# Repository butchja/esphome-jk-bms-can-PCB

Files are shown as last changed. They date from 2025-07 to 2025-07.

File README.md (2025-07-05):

It is recommended to reflow solder with solder paste and stencil. 

Features
- small single board solution
- CAN is now 5V as required by standard
- power supply is compatible to battery voltages now

Materials required
- antenna cable: MHF3 to RP-SMA breakout cable 7cm
- wifi antenna
- BMC cable: JST XH 2.5mm - JST SH 1.25mm
- 2pcs M5 nuts
- 2pc M5x10 screws
- 4pcs M3x5 threaded inserts
- 4pcs M3x6 screws
  



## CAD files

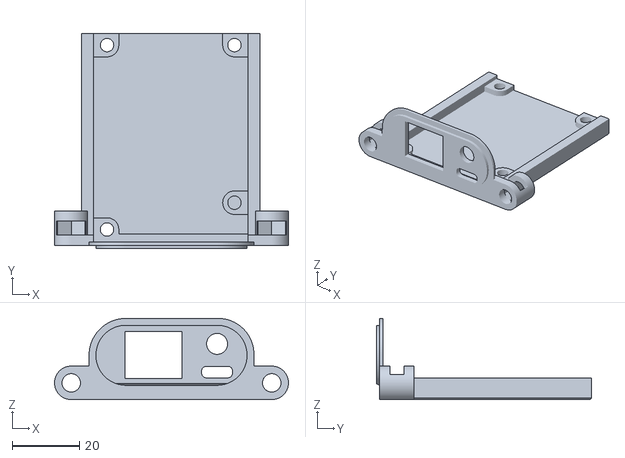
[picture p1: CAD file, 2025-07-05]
HJDC_enclosure_mount.stl
69.8 x 64.2 x 24.2

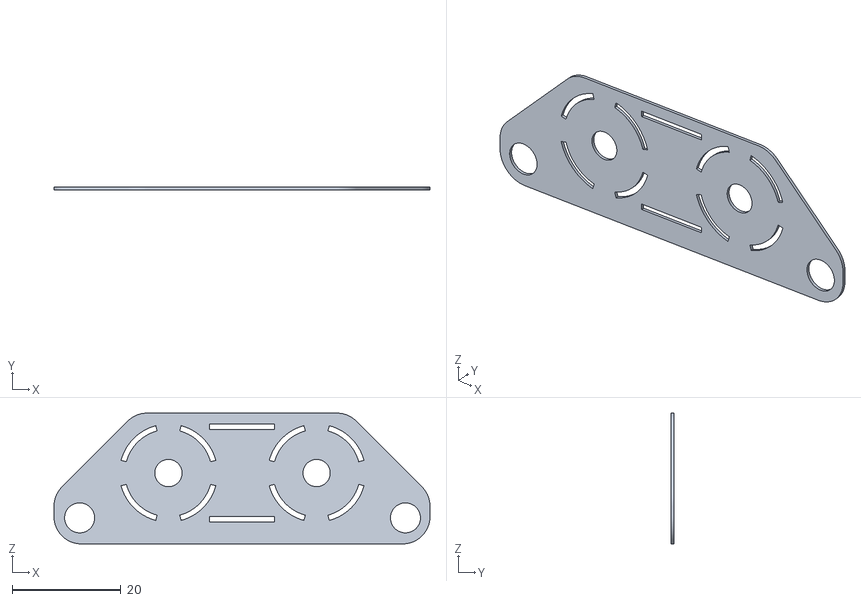
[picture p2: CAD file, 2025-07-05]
HJDC_drillpattern.stl
69.0 x 0.503 x 24.0

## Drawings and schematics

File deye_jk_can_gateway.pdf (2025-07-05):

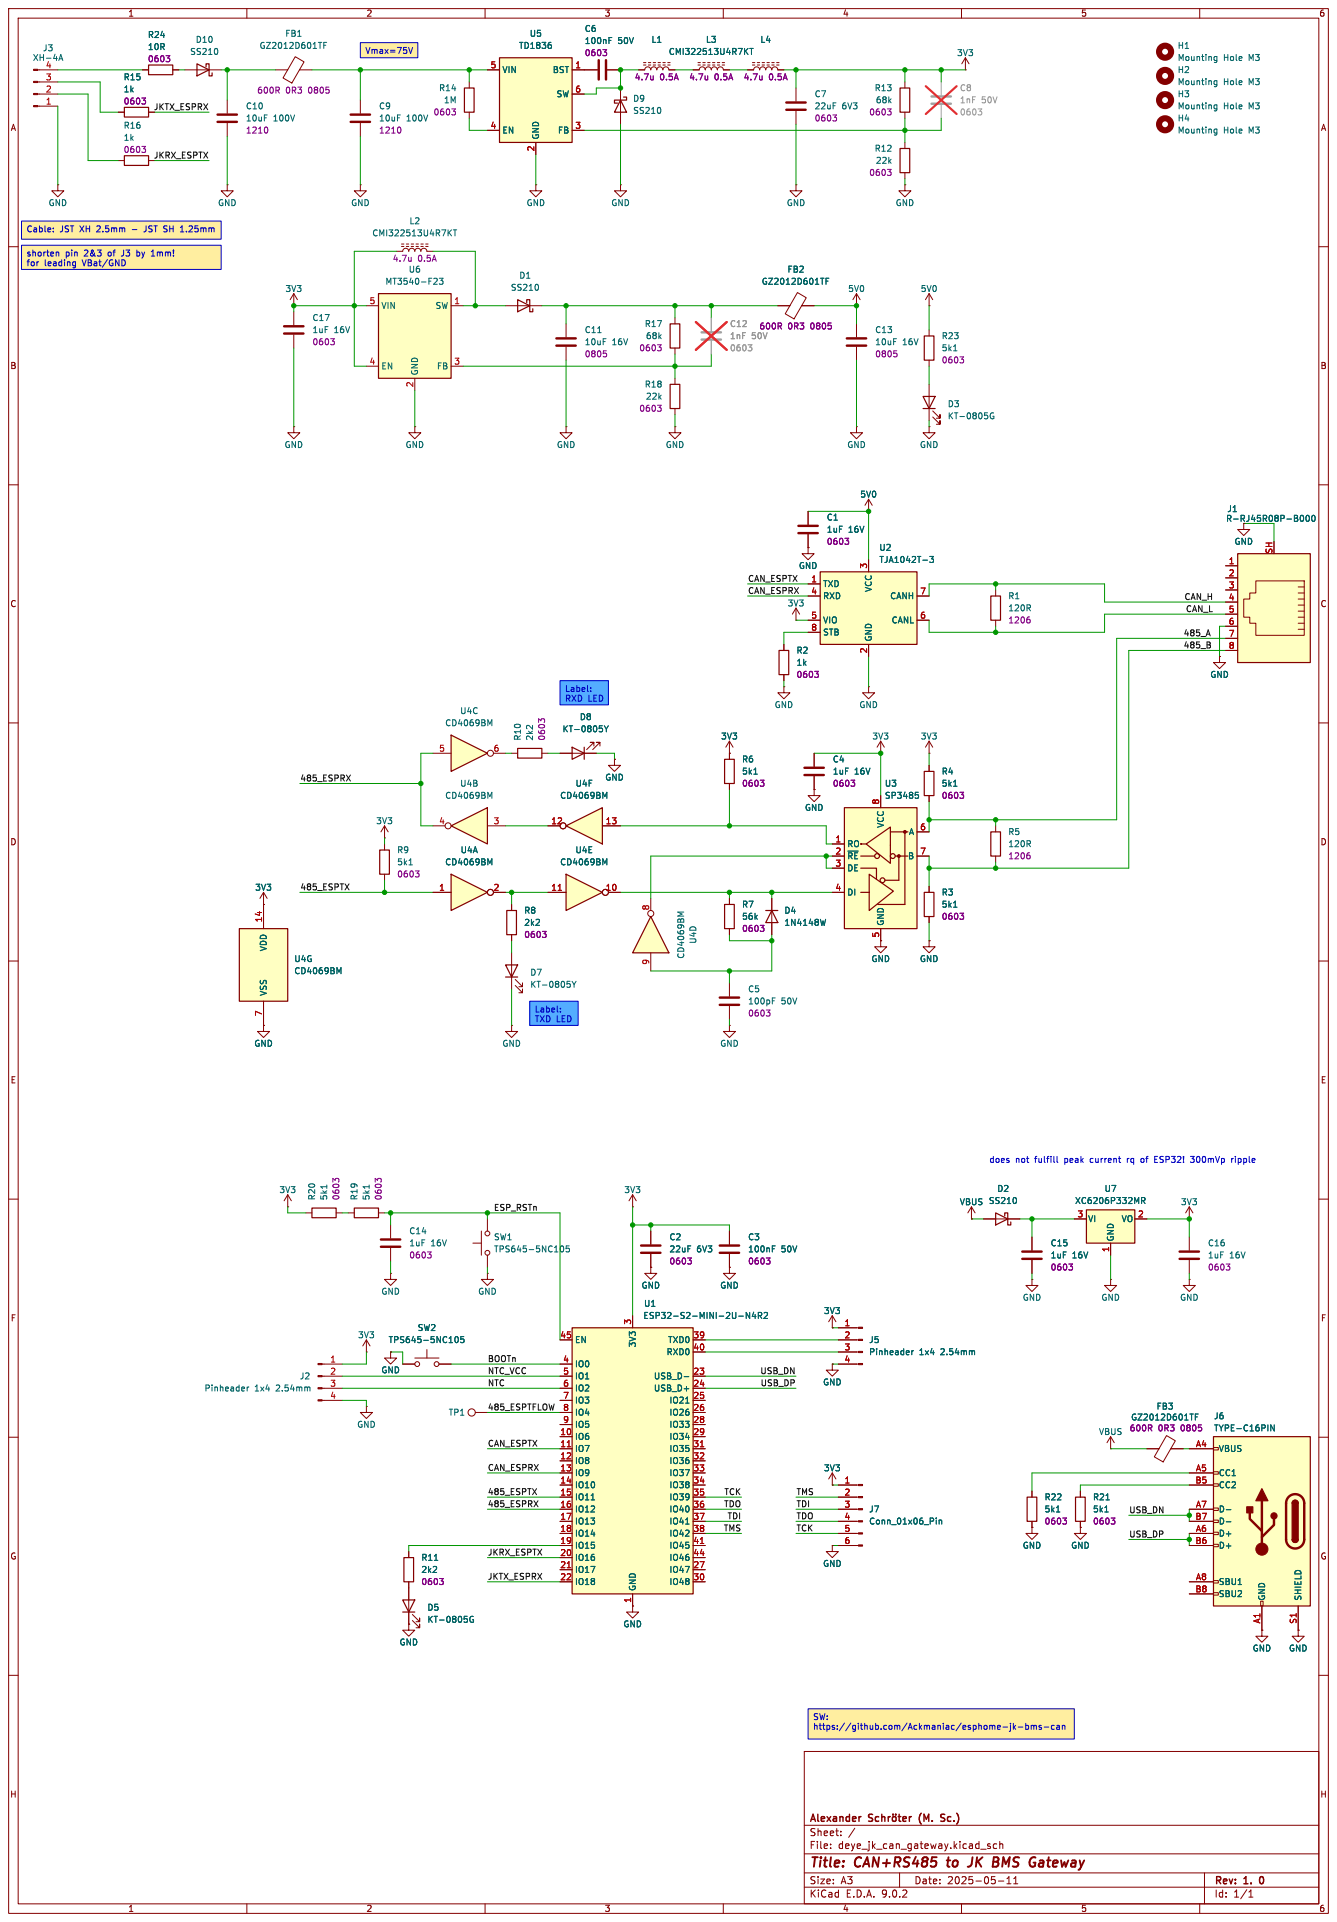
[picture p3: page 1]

2 BST 1 SW 6 FB 3 U5 TD1836 GND GND
Vmax=75V
3V3 GND

Cable: JST XH 2.5mm - JST SH 1.25mm

shorten pin 2&3 of J3 by 1mm!
for leading VBat/GND

SW: https://github.com/Ackmaniac/esphome-jk-bms-can

File: deye_jk_can_gateway.kicad_sch Sheet: / Alexander þÿSchröter (M. Sc.)

Id: 1/1 Title: CAN+RS485 to JK BMS Gateway

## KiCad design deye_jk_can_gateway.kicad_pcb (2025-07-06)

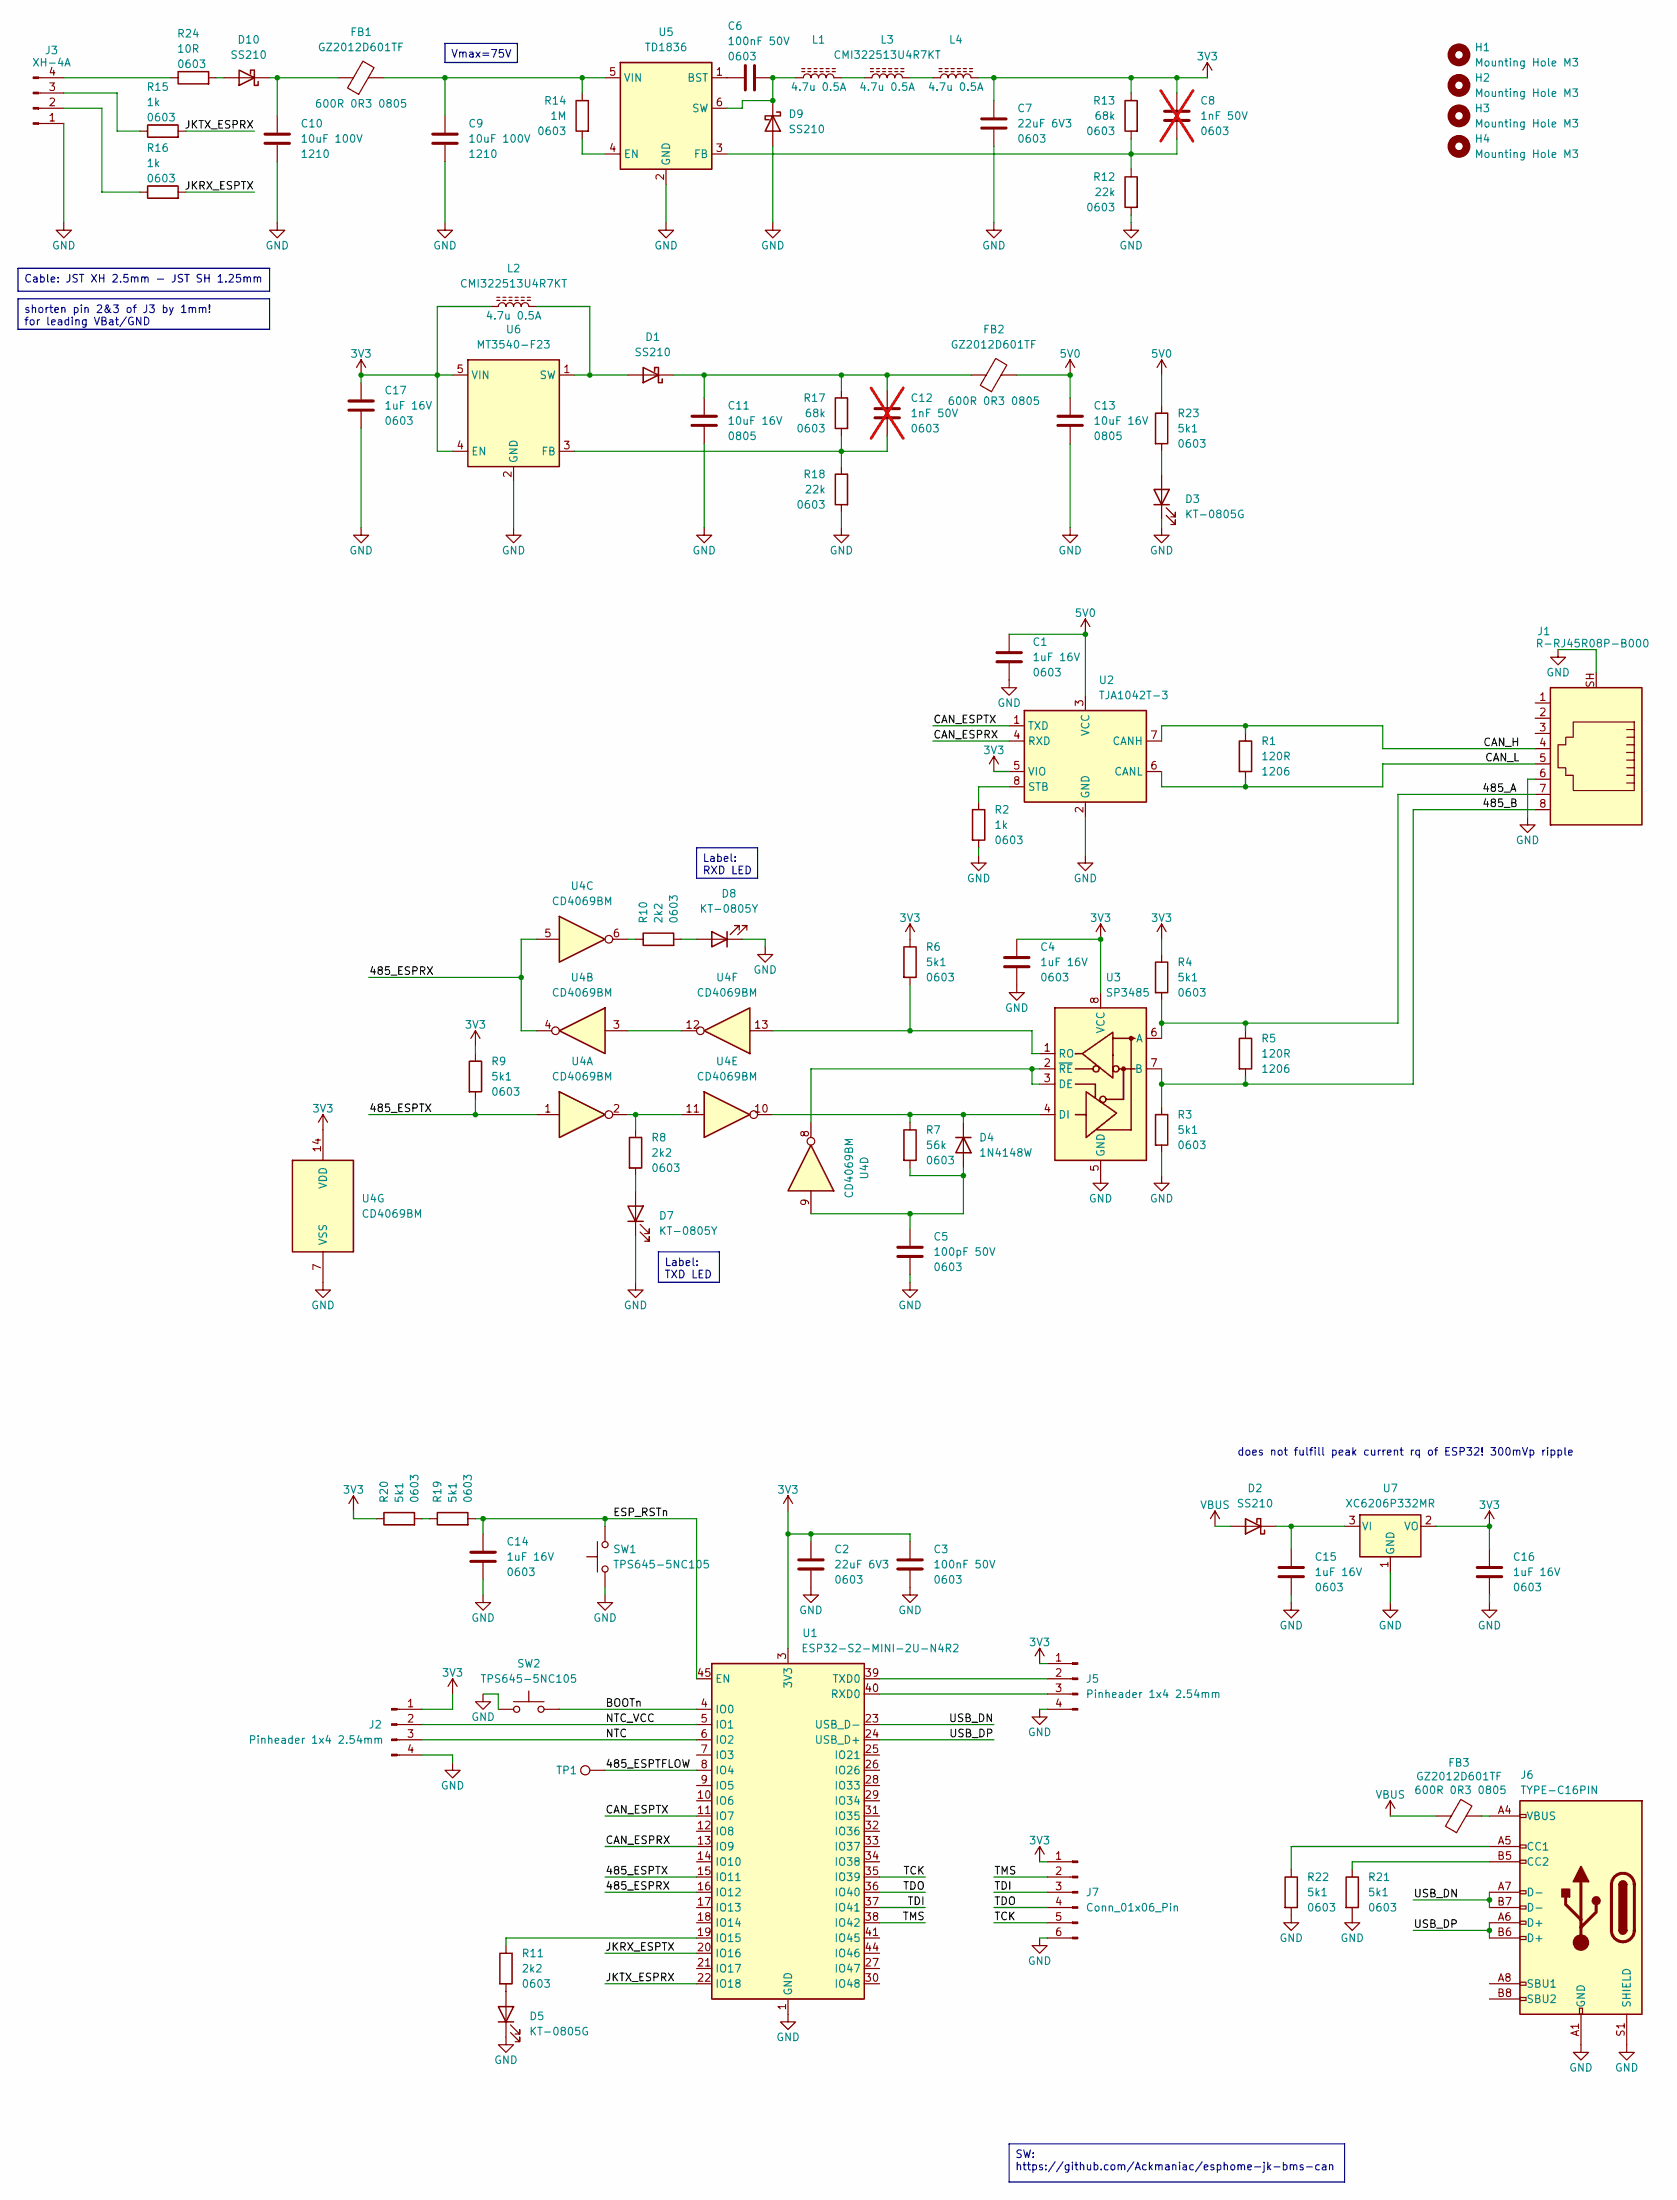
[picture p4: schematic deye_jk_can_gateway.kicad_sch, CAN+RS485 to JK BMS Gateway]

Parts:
C1, C4, C14, C15, C16, C17: 1uF 16V; C_0603_1608Metric; LCSC C1592
C2, C7: 22uF 6V3; C_0603_1608Metric; LCSC C59461
C3, C6: 100nF 50V; C_0603_1608Metric; LCSC C1591
C5: 100pF 50V; C_0603_1608Metric; LCSC C14858
C8, C12: 1nF 50V; C_0603_1608Metric; LCSC C1588; not fitted
C9, C10: 10uF 100V; C_1210_3225Metric; LCSC C576517
C11, C13: 10uF 16V; C_0805_2012Metric; LCSC C1713
D1, D9: SS210; D_SMA
D2, D10: SS210; D_SMA; LCSC C14996
D3, D5: KT-0805G; LED_0805_2012Metric; LCSC C2297
D4: 1N4148W; D_SOD-123; LCSC C2099
D7, D8: KT-0805Y; LED_0805_2012Metric; LCSC C2296
FB1, FB2, FB3: GZ2012D601TF; L_0805_2012Metric; LCSC C1017
H1, H2, H3, H4: Mounting Hole M3; MountingHole_3.2mm_M3_ISO7380
J1: R-RJ45R08P-B000; RJ45_Amphenol_RJHSE5380; LCSC C386756
J2, J5: Pinheader 1x4 2.54mm; PinHeader_1x04_P2.54mm_Vertical
J3: XH-4A; JST_XH_B4B-XH-A_1x04_P2.50mm_Vertical
J6: TYPE-C16PIN; USB_C_Receptacle_GCT_USB4105-xx-A_16P_TopMnt_Horizontal; LCSC C393939
J7: Conn_01x06_Pin; PinHeader_1x06_P2.54mm_Vertical
L1, L2, L3, L4: CMI322513U4R7KT; L_1210_3225Metric; LCSC C60534
R1, R5: 120R; R_1206_3216Metric; LCSC C17909
R2, R15, R16: 1k; R_0603_1608Metric; LCSC C21190
R3, R4, R6, R9, R19, R20, R21, R22, R23: 5k1; R_0603_1608Metric; LCSC C23186
R7: 56k; R_0603_1608Metric; LCSC C23206
R8, R10, R11: 2k2; R_0603_1608Metric; LCSC C4190
R12, R18: 22k; R_0603_1608Metric; LCSC C31850
R13, R17: 68k; R_0603_1608Metric; LCSC C23231
R14: 1M; R_0603_1608Metric; LCSC C22935
R24: 10R; R_0603_1608Metric; LCSC C21190
SW1, SW2: TPS645-5NC105; SW_SPST_PTS645; LCSC C19191549
TP1: TestPoint; TestPoint_Pad_1.0x1.0mm
U1: ESP32-S2-MINI-2U-N4R2; ESP32-S2-MINI-1U; LCSC C3013909
U2: TJA1042T-3; SOIC-8_3.9x4.9mm_P1.27mm; LCSC C132227
U3: SP3485; SOIC-8_3.9x4.9mm_P1.27mm; LCSC C8963
U4: CD4069BM; SOIC-14_3.9x8.7mm_P1.27mm; LCSC C22384785
U5: TD1836; SOT-23-6; LCSC C2935198
U6: MT3540-F23; SOT-23-5; LCSC C181783
U7: XC6206P332MR; SOT-23-3; LCSC C5446

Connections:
3V3: C2.1, C3.1, C4.1, C7.1, C8.1, C16.1, C17.1, J2.1, J5.1, J7.1, L2.1, L4.2, R4.1, R6.1, R9.1, R13.1, R20.1, U1.3 (3V3), U2.5 (VIO), U3.8 (VCC), U4.14 (VDD), U6.4 (EN), U6.5 (VIN), U7.2 (VO)
5V0: C1.1, C13.1, FB2.2, R23.1, U2.3 (VCC)
/485_A: J1.7, R4.2, R5.1, U3.6 (A)
/485_B: J1.8, R3.1, R5.2, U3.7 (B)
/485_ESPRX: U1.16 (IO12), U4.4, U4.5
/485_ESPTFLOW: TP1.1, U1.8 (IO4)
/485_ESPTX: R9.2, U1.15 (IO11), U4.1
/BOOTn: SW2.2, U1.4 (IO0)
/CAN_ESPRX: U1.13 (IO9), U2.4 (RXD)
/CAN_ESPTX: U1.11 (IO7), U2.1 (TXD)
/CAN_H: J1.4, R1.1, U2.7 (CANH)
/CAN_L: J1.5, R1.2, U2.6 (CANL)
/ESP_RSTn: C14.1, R19.2, SW1.2, U1.45 (EN)
/JKRX_ESPTX: R16.2, U1.20 (IO16)
/JKTX_ESPRX: R15.2, U1.22 (IO18)
/NTC: J2.3, U1.6 (IO2)
/NTC_VCC: J2.2, U1.5 (IO1)
/TCK: J7.5, U1.35 (IO39)
/TDI: J7.3, U1.37 (IO41)
/TDO: J7.4, U1.36 (IO40)
/TMS: J7.2, U1.38 (IO42)
/USB_DN: J6.A7 (D-), J6.B7 (D-), U1.23 (USB_D-)
/USB_DP: J6.A6 (D+), J6.B6 (D+), U1.24 (USB_D+)
GND: C1.2, C2.2, C3.2, C4.2, C5.2, C7.2, C9.2, C10.2, C11.2, C13.2, C14.2, C15.2, C16.2, C17.2, D3.1 (K), D5.1 (K), D7.1 (K), D8.1 (K), D9.2 (A), J1.6, J1.SH, J2.4, J3.1, J5.4, J6.A1 (GND), J6.A12 (GND), J6.B1 (GND), J6.B12 (GND), J6.S1 (SHIELD), J7.6, R2.2, R3.2, R12.2, R18.2, R21.2, R22.2, SW1.1, SW2.1, U1.1 (GND), U1.2 (GND), U1.42 (GND), U1.43 (GND), U1.46 (GND), U1.47 (GND), U1.48 (GND), U1.49 (GND), U1.50 (GND), U1.51 (GND), U1.52 (GND), U1.53 (GND), U1.54 (GND), U1.55 (GND), U1.56 (GND), U1.57 (GND), U1.58 (GND), U1.59 (GND), U1.60 (GND), U1.61 (GND), U1.62 (GND), U1.63 (GND), U1.64 (GND), U1.65 (GND), U2.2 (GND), U3.5 (GND), U4.7 (VSS), U5.2 (GND), U6.2 (GND), U7.1 (GND)
unnamed: D1.2 (A), L2.2, U6.1 (SW)
unnamed: C11.1, C12.1, D1.1 (K), FB2.1, R17.1
unnamed: C15.1, D2.1 (K), U7.3 (VI)
unnamed: D3.2 (A), R23.2
unnamed: C5.1, D4.2 (A), R7.2, U4.9
unnamed: D4.1 (K), R7.1, U3.4 (DI), U4.10
unnamed: D5.2 (A), R11.2
unnamed: D7.2 (A), R8.2
unnamed: D8.2 (A), R10.2
unnamed: C6.2, D9.1 (K), L1.1, U5.6 (SW)
unnamed: D10.2 (A), R24.2
unnamed: C10.1, D10.1 (K), FB1.1
unnamed: FB3.2, J6.A4 (VBUS), J6.A9 (VBUS), J6.B4 (VBUS), J6.B9 (VBUS)
unnamed: J3.2, R16.1
unnamed: J3.3, R15.1
unnamed: J3.4, R24.1
unnamed: J5.2, U1.39 (TXD0)
unnamed: J5.3, U1.40 (RXD0)
unnamed: J6.A5 (CC1), R22.1
unnamed: J6.B5 (CC2), R21.1
unnamed: L1.2, L3.1
unnamed: L3.2, L4.1
unnamed: R8.1, U4.2, U4.11
unnamed: R10.1, U4.6
unnamed: R19.1, R20.2
unnamed: R11.1, U1.19 (IO15)
unnamed: R2.1, U2.8 (STB)
unnamed: U3.2 (~RE), U3.3 (DE), U4.8
unnamed: R6.2, U3.1 (RO), U4.13
unnamed: U4.3, U4.12
unnamed: C6.1, U5.1 (BST)
unnamed: R14.2, U5.4 (EN)
unnamed: C8.2, R12.1, R13.2, U5.3 (FB)
unnamed: C9.1, FB1.2, R14.1, U5.5 (VIN)
unnamed: C12.2, R17.2, R18.1, U6.3 (FB)
VBUS: D2.2 (A), FB3.1

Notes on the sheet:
does not fulfill peak current rq of ESP32! 300mVp ripple
Label: RXD LED
shorten pin 2&3 of J3 by 1mm! for leading VBat/GND
Label: TXD LED
Cable: JST XH 2.5mm - JST SH 1.25mm
SW: https://github.com/Ackmaniac/esphome-jk-bms-can
Vmax=75V

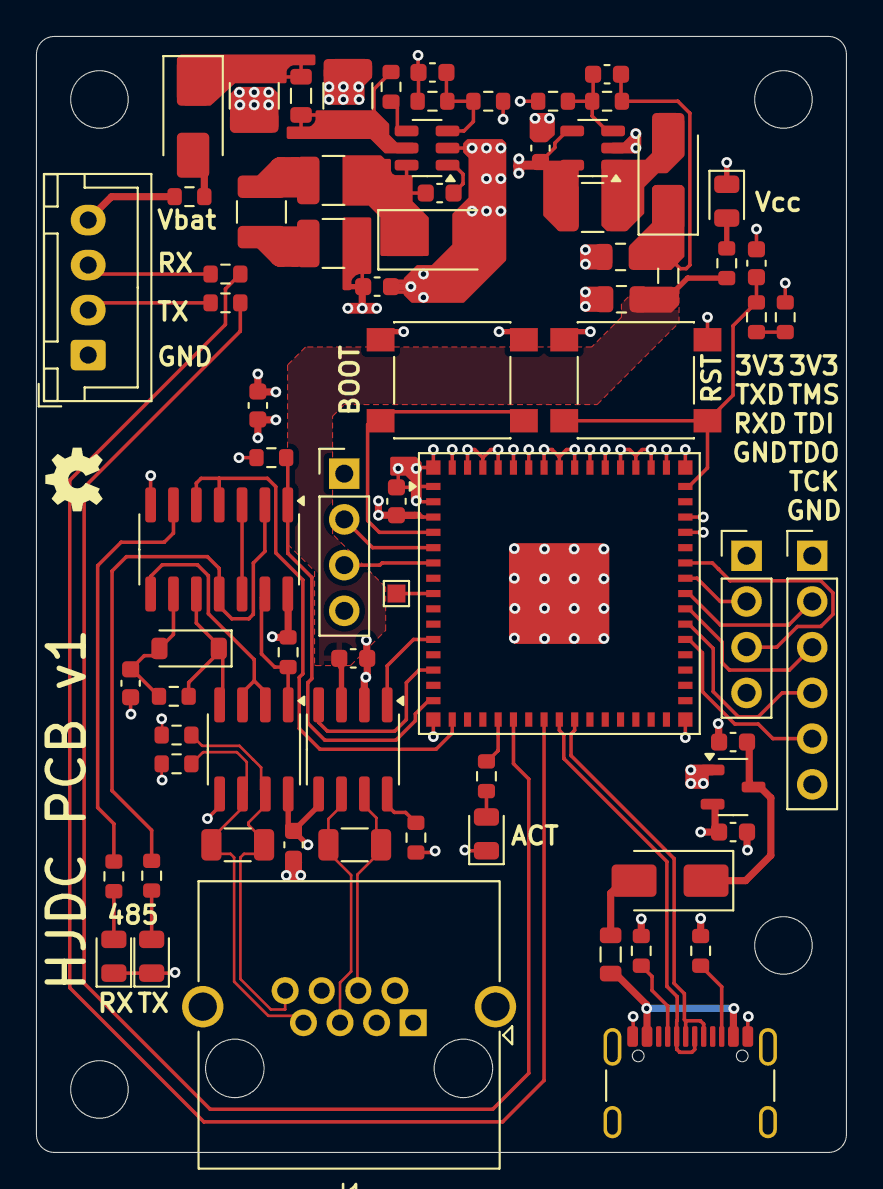
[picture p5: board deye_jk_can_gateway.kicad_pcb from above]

Board: 4 copper layers, 45.0 x 62.0 mm, 77 parts (0 on the bottom side), 60 nets.

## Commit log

2025-07-05 commit after built successful prototype
    KiCAD project and Design Spark Mechanical PCB Holder.
    [HJDC_drillpattern.stl, HJDC_enclosure_mount.stl, deye_jk_can_gateway.kicad_pcb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]
2025-07-06 filled ground plane
    [deye_jk_can_gateway.kicad_pcb]
